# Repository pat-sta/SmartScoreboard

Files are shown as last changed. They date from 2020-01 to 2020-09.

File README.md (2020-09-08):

# SmartScoreboard
Fully custom-made programmable scoreboard featuring a real-time-clock and games such as Ping-Pong, Baseball, Die Toss.  
[Arduino Code](https://github.com/pat-stach/SmartScoreboard/tree/master/src/SmartScoreboard) | [3D Models](https://github.com/pat-stach/SmartScoreboard/tree/master/src/3D%20Models)


## The Team
**Patrick Stach** | stach2@illinois.edu    
Circuit design and wiring, programming scoreboard.

**Thomas Schneider** | thomass8@illinois.edu    
Scoreboard enclosure design and build, CAD design of modular housings/ enclosures.

## Portfolio
See the scoreboard in action and learn about specific parts of the build through video and pictures.  
https://illinois.digication.com/smart-scoreboard/home

Scoreboard in Action (https://illinois.digication.com/smart-scoreboard/scoreboard-in-action)

## Parts Used
| Part | Purpose | Vendor Link |
|---|---|---|
| Arduino Nano Board ATmega328P | Programmed for game logic and reading/controlling outputs/inputs | [Amazon](https://www.amazon.com/Arduino-A000005-ARDUINO-Nano/dp/B0097AU5OU/) |
| SparkFun 6.5" 7-Segment Display | Display numbers such as score, time, etc. | [SparkFun](https://www.sparkfun.com/products/11441) |
| SparkFun Large Digit Driver | Controller to drive 7-Segment displays and store segment data in shift register | [SparkFun](https://www.sparkfun.com/products/13279) |
| SN74HC595 Shift Register | Controls panel LEDs | [SparkFun](https://www.sparkfun.com/products/13699) |
| SN74HC165 Shift Register | Used to take "snapshot" of button states | [Amazon](https://www.amazon.com/SN74HC165N-74HC165-8-Bit-Parallel-Load-Registers/dp/B00UVUXIV2)  |
| 12V DC Switching Power Supply | 120V AC -> 12V DC converter | [Amazon](https://www.amazon.com/Chanzon-Switching-Adapter-100-240V-Transformer/dp/B07HNL5D56/) |
| LM2596 DC to DC Buck Converter  | 12V DC -> 5V DC for 5V components/logic, 12V DC -> 11V DC to dim 7-segment displays | [Amazon](https://www.amazon.com/LM2596s-Converter-Step-down-Regulator-Stabilizer/dp/B07CVBG8CT/) |
| DS3231 RTC Module | Stores time/date information even when scoreboard is off | [Amazon](https://www.amazon.com/gp/product/B01IXYM3PY/) |
| 12V LED Panel Lights | Lights to indicate game data such as round, outs, bases, etc. | [Amazon](https://www.amazon.com/gp/product/B07DH943VR/) |
| 5V Relay Board | Control 12V LED Panel lights from Arduino | [Amazon](https://www.amazon.com/gp/product/B07QGT6RGX/) |
| Arcade Push Buttons | 5 Buttons for each team to control scoreboard | [Amazon](https://www.amazon.com/gp/product/B01M0XPWGG/) |

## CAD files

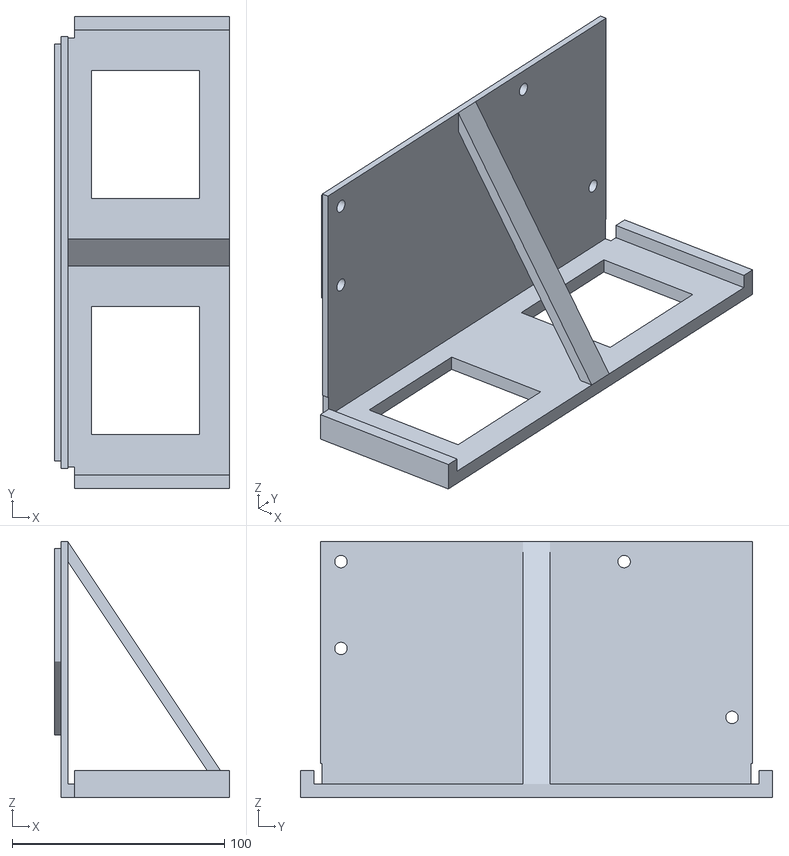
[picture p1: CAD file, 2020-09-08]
src/3D Models/control_panelv3_sidecover.stl
82.6 x 222.3 x 120.6

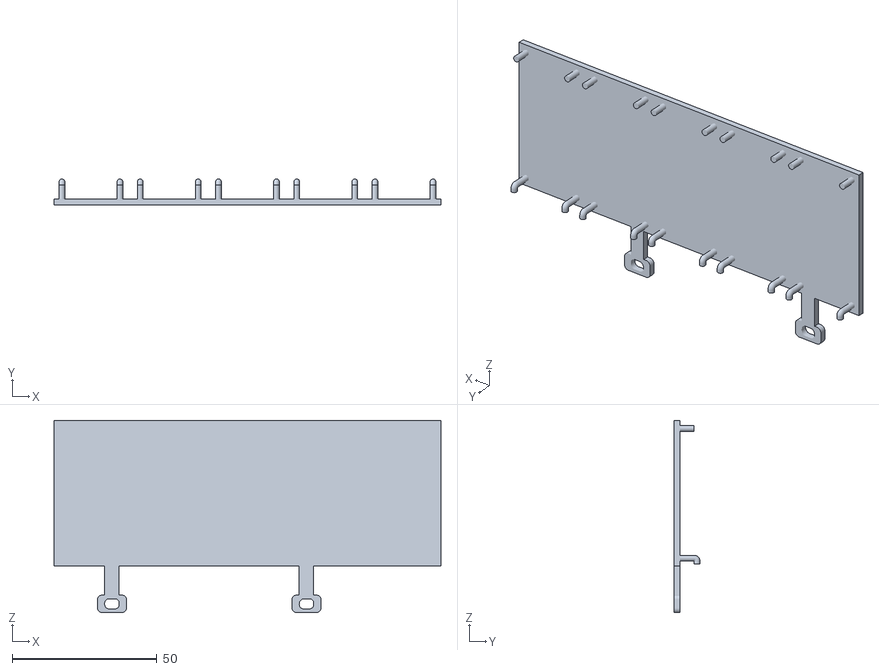
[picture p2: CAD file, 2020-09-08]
src/3D Models/relay_holder_5l.stl
133.5 x 9.00 x 66.2

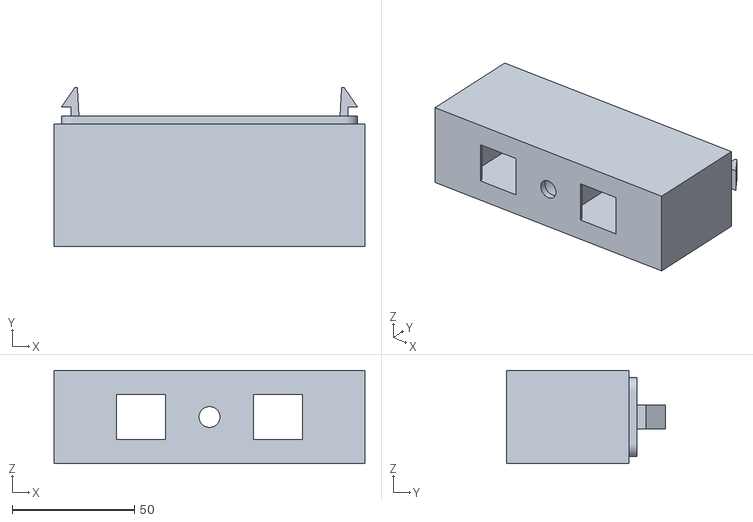
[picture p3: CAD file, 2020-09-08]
src/3D Models/modular_box.stl
127.0 x 65.0 x 38.1

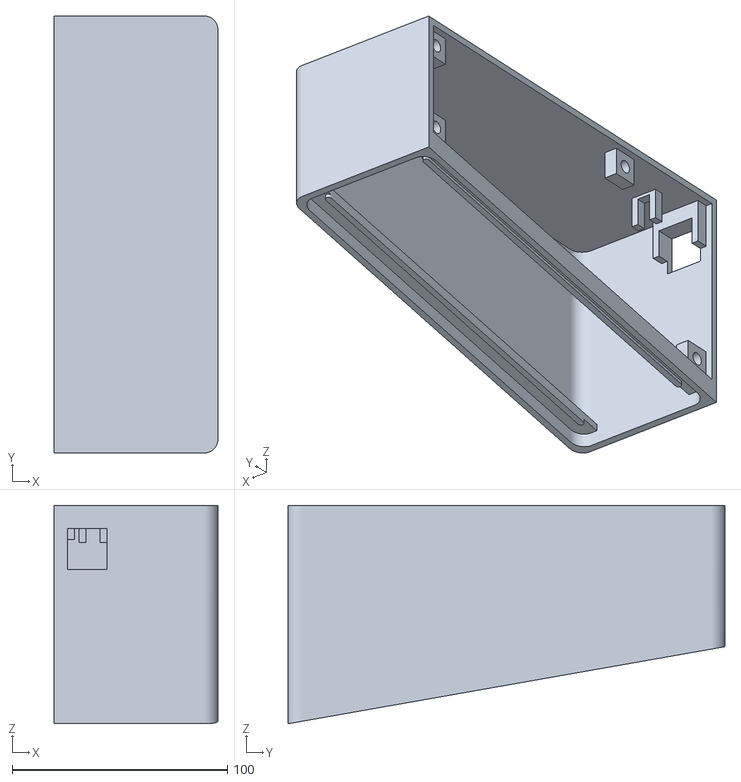
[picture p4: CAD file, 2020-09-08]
src/3D Models/control_panel_v3.stl
76.2 x 203.2 x 101.6

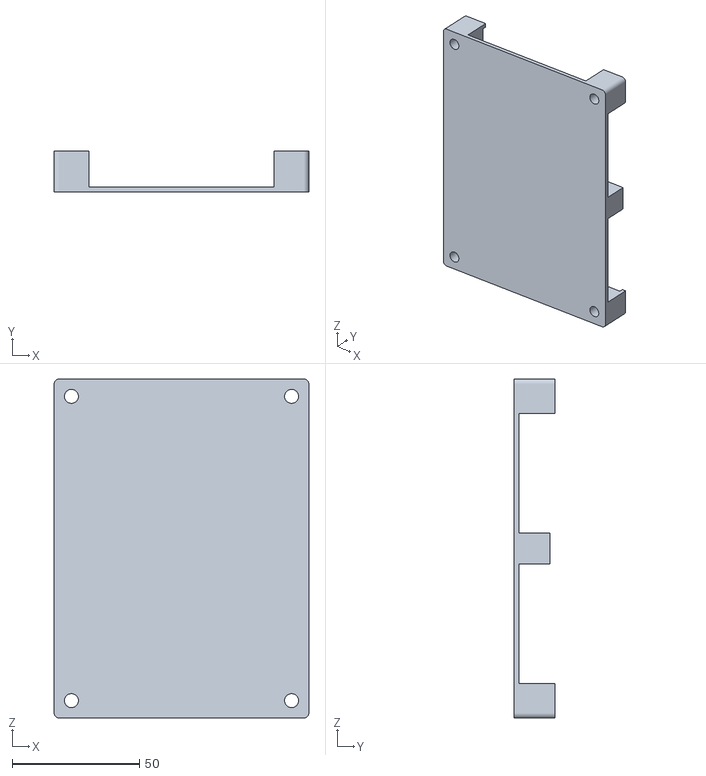
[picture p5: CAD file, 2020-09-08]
src/3D Models/proto_holder.stl
100.0 x 16.0 x 133.0

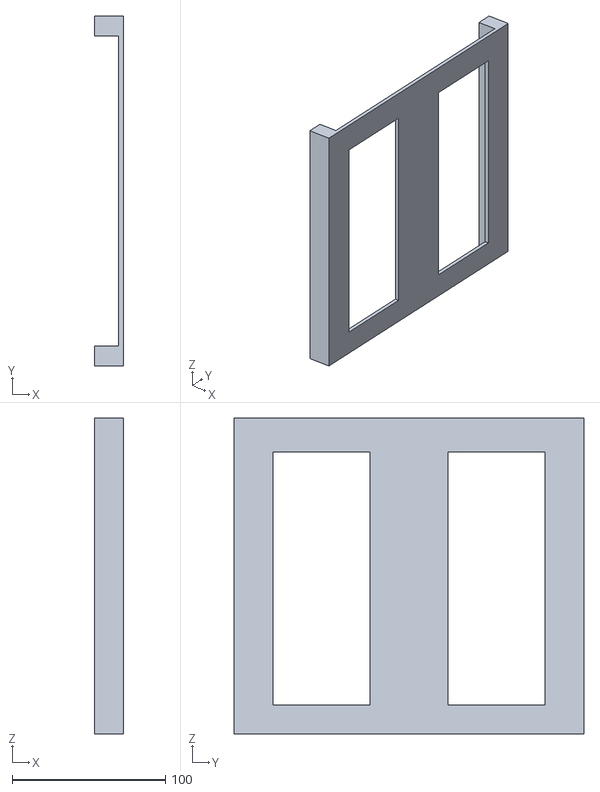
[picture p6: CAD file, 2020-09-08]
src/3D Models/rail3.stl
19.0 x 228.6 x 206.4

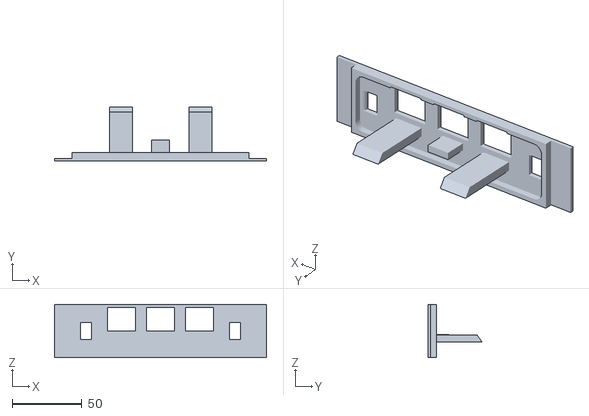
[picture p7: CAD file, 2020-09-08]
src/3D Models/modular__cover.stl
152.4 x 39.0 x 38.1

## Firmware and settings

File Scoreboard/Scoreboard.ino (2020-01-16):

//final
//MSB is

/*  data = ABCDEFGH
    MSB -> LSB
         H
       ---
    G | F | B
       ---
    E |   | C
       ---  o A
        D
*/
/*
  Controlling large 7-segment displays
  By: Nathan Seidle
  SparkFun Electronics
  Date: February 25th, 2015
  License: This code is public domain but you buy me a beer if you use this and we meet someday (Beerware license).

  This code demonstrates how to post two numbers to a 2-digit display usings two large digit driver boards.

  Here's how to hook up the Arduino pins to the Large Digit Driver IN

  Arduino pin 6 -> CLK (Green on the 6-pin cable)
  5 -> LAT (Blue)
  7 -> SER on the IN side (Yellow)
  5V -> 5V (Orange)
  Power Arduino with 12V and connect to Vin -> 12V (Red)
  GND -> GND (Black)

  There are two connectors on the Large Digit Driver. 'IN' is the input side that should be connected to
  your microcontroller (the Arduino). 'OUT' is the output side that should be connected to the 'IN' of addtional
  digits.

  Each display will use about 150mA with all segments and decimal point on.

*/
void postNumber(byte number, boolean decimal);
void LatchData(byte segmentLatch);
void showBlank(int time_amt);
void loopNumpers(int time_amt, int num_times);

//GPIO declarations
//-=-=-=-=-=-=-=-=-=-=-=-=-=-=-=-=-=-=-=-=-=-=-=-=
byte segmentLatch = 4;
byte segmentClock = 3;
byte segmentData = 2;


//-=-=-=-=-=-=-=-=-=-=-=-=-=-=-=-=-=-=-=-=-=-=-=-=
//Button Value declarations



void setup()
{
  Serial.begin(9600);
  Serial.println("Large Digit Driver Example");

  pinMode(segmentClock, OUTPUT);
  pinMode(segmentData, OUTPUT);
  pinMode(segmentLatch, OUTPUT);



  digitalWrite(segmentClock, LOW);
  digitalWrite(segmentData, LOW);
  digitalWrite(segmentLatch, LOW);






}

void loop()
{

  delay(1500);
  digitalWrite(segmentLatch, LOW);
  showWord('e','c','e',' ');
  digitalWrite(segmentLatch, HIGH);

  delay(1500);

  digitalWrite(segmentLatch, LOW);
  showWord('b','o','y','s');
  digitalWrite(segmentLatch, HIGH);


}


//Given a number, or '-', shifts it out to the display
void postNumber(byte number)
{
  byte segments;
  switch (number)
  {
    //Numbers
    case 1: segments = 0b01100000; break;
    case 2: segments = 0b01011101; break;
    case 3: segments = 0b01110101; break;
    case 4: segments = 0b01100110; break;
    case 5: segments = 0b00110111; break;
    case 6: segments = 0b00111111; break;
    case 7: segments = 0b01100001; break;
    case 8: segments = 0b01111111; break;
    case 9: segments = 0b01110111; break;
    case 0: segments = 0b01111011; break;

    case ' ': segments = 0b00000000; break;
    
    case 'a': segments = 0b01101111; break;
    case 'b': segments = 0b00111110; break;
    case 'c': segments = 0b00011011; break;
    case 'd': segments = 0b01111100; break;
    case 'e': segments = 0b00011111; break;
    case 'f': segments = 0b00001111; break;
    case 'g': segments = 0b01110111; break;
    case 'h': segments = 0b00101110; break;
    case 'i': segments = 0b01100000; break;
    case 'j': segments = 0b01110000; break;
    case 'k': segments = 0b00101111; break;
    case 'l': segments = 0b00011010; break;
    case 'm': segments = 0b00101001; break;
    case 'n': segments = 0b01101011; break;
    case 'o': segments = 0b01111011; break;
    case 'p': segments = 0b01001111; break;
    case 'q': segments = 0b01100111; break;
    case 'r': segments = 0b00001011; break; // make lowercase?
    case 's': segments = 0b00110111; break;
    case 't': segments = 0b00011110; break;
    case 'u': segments = 0b01111010; break;
    case 'v': segments = 0b00111000; break;
    case 'w': segments = 0b00111001; break;
    case 'x': segments = 0b01101110; break;
    case 'y': segments = 0b01110110; break;
    case 'z': segments = 0b01011101; break;
  }
  
  //Clock these bits out to the drivers
  for (byte x = 0 ; x < 8 ; x++)
  {
    digitalWrite(segmentClock, LOW);
    digitalWrite(segmentData, segments & 1 << (7 - x));
    digitalWrite(segmentClock, HIGH); //Data transfers to the register on the rising edge of SRCK
  }
}

void postNumber(byte number, boolean decimal)
{
  byte segments;
  switch (number)
  {
    case 1: segments = 0b01100000; break;
    case 2: segments = 0b01011101; break;
    case 3: segments = 0b01110101; break;
    case 4: segments = 0b01100110; break;
    case 5: segments = 0b00110111; break;
    case 6: segments = 0b00111111; break;
    case 7: segments = 0b01100001; break;
    case 8: segments = 0b01111111; break;
    case 9: segments = 0b01110111; break;
    case 0: segments = 0b01111011; break;

    case ' ': segments = 0b00000000; break;
    
    case 'a': segments = 0b01101111; break;
    case 'b': segments = 0b00111110; break;
    case 'c': segments = 0b00011011; break;
    case 'd': segments = 0b01111100; break;
    case 'e': segments = 0b00011111; break;
    case 'f': segments = 0b00001111; break;
    case 'g': segments = 0b01110111; break;
    case 'h': segments = 0b00101110; break;
    case 'i': segments = 0b01100000; break;
    case 'j': segments = 0b01110000; break;
    case 'k': segments = 0b00101111; break;
    case 'l': segments = 0b00011010; break;
    case 'm': segments = 0b00101001; break;
    case 'n': segments = 0b01101011; break;
    case 'o': segments = 0b01111011; break;
    case 'p': segments = 0b01001111; break;
    case 'q': segments = 0b01100111; break;
    case 'r': segments = 0b00001011; break; // make lowercase?
    case 's': segments = 0b00110111; break;
    case 't': segments = 0b00011110; break;
    case 'u': segments = 0b01111010; break;
    case 'v': segments = 0b00111000; break;
    case 'w': segments = 0b00111001; break;
    case 'x': segments = 0b01101110; break;
    case 'y': segments = 0b01110110; break;
    case 'z': segments = 0b01011101; break;
  }
  segments = segments + 0b10000000;
  //Clock these bits out to the drivers
  for (byte x = 0 ; x < 8 ; x++)
  {
    digitalWrite(segmentClock, LOW);
    digitalWrite(segmentData, segments & 1 << (7 - x));
    digitalWrite(segmentClock, HIGH); //Data transfers to the register on the rising edge of SRCK
  }
}

void showWord(byte char1, byte char2, byte char3, byte char4)
{
  postNumber(char4);
  postNumber(char3);
  postNumber(char2);
  postNumber(char1);
}

void showNumber(float value) {
  int remainder;
  int number = abs(value);
  for (byte x = 0 ; x < 4 ; x++) {
    remainder = number % 10;
    postNumber(remainder);
    number /= 10;
  }
}

void showNumber(float value1, float value2) {
  int remainder;
  int number = abs(value2);
  for (byte x = 0 ; x < 2 ; x++) {
    remainder = number % 10;
    postNumber(remainder);
    number /= 10;
  }
  number = abs(value1);
  for (byte x = 0 ; x < 2 ; x++) {
    remainder = number % 10;
    postNumber(remainder);
    number /= 10;
  }
}


//void showNumber(float value1, float value2, float value3, float value4) {
//  int remainder;
//  postNumber(abs(value4));
//  postNumber(abs(value3));
//  postNumber(abs(value2));
//  postNumber(abs(value1));
//
//}



void LatchData(byte segmentLatch)
{
  digitalWrite(segmentLatch, LOW);
  digitalWrite(segmentLatch, HIGH);
}


void showBlank(int time_amt)
{
  postNumber(' ', false);
  postNumber(' ', false);
  postNumber(' ', false);
  postNumber(' ', false);
  LatchData(segmentLatch);
  delay(time_amt);
}


void loopNumpers(int time_amt, int num_times)
{
  for (int ctr = 0; ctr < num_times; ctr++) {
    for (int i = 0; i < 10; i++) {
      for (int j = 0; j < 4; j++) {
        postNumber(i, false);
      }
      LatchData(segmentLatch);
      delay(time_amt);
    }
  }
}

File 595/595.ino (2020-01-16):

//final
//**************************************************************//
//  Name    : shiftOutCode, Dual Binary Counters                 //
//  Author  : Carlyn Maw, Tom Igoe                               //
//  Date    : 25 Oct, 2006                                       //
//  Version : 1.0                                                //
//  Notes   : Code for using a 74HC595 Shift Register            //
//          : to count from 0 to 255                             //
//**************************************************************//

//Pin connected to ST_CP of 74HC595
int latchPin = 15; //yellow
//Pin connected to SH_CP of 74HC595
int clockPin = 16; //green
////Pin connected to DS of 74HC595
int dataPin = 17; //blue



void setup() {
  //Start Serial for debuging purposes  
  Serial.begin(9600);
  //set pins to output because they are addressed in the main loop
  pinMode(latchPin, OUTPUT);

}



byte round_shift_out( int t1_round, int t2_round)
{
        if (t1_round ==0 && t2_round ==0) return 0b000000;
   else if (t1_round ==0 && t2_round ==1) return 0b000001;
   else if (t1_round ==0 && t2_round ==2) return 0b000011;
   else if (t1_round ==0 && t2_round ==3) return 0b000111;
  
  else if (t1_round ==1 && t2_round ==0) return 0b100000;
  else if (t1_round ==1 && t2_round ==1) return 0b100100;
  else if (t1_round ==1 && t2_round ==2) return 0b100110;
  else if (t1_round ==1 && t2_round ==3) return 0b100111;
  

  else if (t1_round ==2 && t2_round ==0) return 0b110000;
  else if (t1_round ==2 && t2_round ==1) return 0b110100;
  else if (t1_round ==2 && t2_round ==2) return 0b110110;
  else if (t1_round ==2 && t2_round ==3) return 0b110111;

   else if (t1_round ==3 && t2_round ==0) return 0b111000;
  else if (t1_round ==3 && t2_round ==1) return 0b111100;
  else if (t1_round ==3 && t2_round ==2) return 0b111110;
  else return 0b111111;
}



byte round_SR;
byte base_SR;
void loop() {
  //count up routine
   
  
    Serial.println("-");
    //ground latchPin and hold low for as long as you are transmitting
    digitalWrite(latchPin, 0);
    
    //round LEDs
    shiftOut(dataPin, clockPin,  0b111000); 
    //base LEDs
    shiftOut(dataPin, clockPin, 0b0100);
    digitalWrite(latchPin, 1);

    Serial.println();
    delay(1000);
     digitalWrite(latchPin, 0);
    //round LEDs
    shiftOut(dataPin, clockPin,  0b010101); 
    //base LEDs
    shiftOut(dataPin, clockPin, 0b1010);
    
    
    digitalWrite(latchPin, 1);

    Serial.println();
    delay(1000);

    
 
}

void shiftOut(int myDataPin, int myClockPin, byte myDataOut) {
  // This shifts 8 bits out MSB first, 
  //on the rising edge of the clock,
  //clock idles low

//internal function setup
  int i=0;
  int pinState;
  pinMode(myClockPin, OUTPUT);
  pinMode(myDataPin, OUTPUT);

 //clear everything out just in case to
 //prepare shift register for bit shifting
  digitalWrite(myDataPin, 0);
  digitalWrite(myClockPin, 0);

  //for each bit in the byte myDataOut�
  //NOTICE THAT WE ARE COUNTING DOWN in our for loop
  //This means that %00000001 or "1" will go through such
  //that it will be pin Q0 that lights. 
  for (i=7; i>=0; i--)  {
    digitalWrite(myClockPin, 0);

    //if the value passed to myDataOut and a bitmask result 
    // true then... so if we are at i=6 and our value is
    // %11010100 it would the code compares it to %01000000 
    // and proceeds to set pinState to 1.
    if ( myDataOut & (1<<i) ) {
      pinState= 1;
    }
    else {  
      pinState= 0;
    }

    //Sets the pin to HIGH or LOW depending on pinState
    digitalWrite(myDataPin, pinState);
    //register shifts bits on upstroke of clock pin  
    digitalWrite(myClockPin, 1);
    //zero the data pin after shift to prevent bleed through
    digitalWrite(myDataPin, 0);
  }

  //stop shifting
  digitalWrite(myClockPin, 0);
}

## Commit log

2020-01-02 Scoreboard w/ pins as buttons, 165 button code
2020-01-04 595 code and wiring done, cant figure out +1 bug
    [595.ino, 7seg.ino]
2020-01-05 Fixed 595 wiring, used 0b notation
    [595.ino]
2020-01-05 Fixed Wiring: MSB of Round on left, MSB of bases is Home (H,1,2,3)
    [595.ino]
2020-01-05 Added button registration, rising edge indicator, hit type. Added skeleton for base transitions
2020-01-16 Classes buttons, outputsr, inputsr
2020-01-16 Button Pressed on single button- rough single press, double press, hold working
2020-01-18 Fixed button registration all cases, need to change debug prints, add button LED on/off for generic case instead of 6
2020-01-18 Update with example button press code to display
2020-08-25 Switch btw ping pong, clock
2020-09-08 Added 3D Files
    [control_panel_v3.stl, control_panelv3_sidecover.stl, modular__cover.stl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]
